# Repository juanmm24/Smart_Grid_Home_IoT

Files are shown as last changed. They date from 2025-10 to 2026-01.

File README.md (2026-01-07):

*** Repository Description *** 

This repository contains all the materials required for the development of an IoT-Based Residential Electricity Consumption Monitoring and Management System.

*** The system is composed of two main nodes *** 

- Node 1: Responsible for measuring electrical consumption and remotely managing household appliances.

- Node 2: Responsible for measuring the overall household electricity consumption and remotely managing electrical circuits.

*** Electronic Components ***

- ESP32 Module

- PZEM-004T V3 Sensor

- 2-Channel Relay Module

- Solid-State Relays (SSR)

* For more details on the electrical connections and circuit diagrams for each node, refer to the folder “Diagrama de Circuitos” (Circuit Diagram).

*** InfluxDB Database Files ***

The data stored in InfluxDB are divided into 10 split archive files, each identified by a numerical suffix in its folder name.
To access them:

1. Download all parts and place them in the same folder.

2. Open only the file smart_grid_home_parted.7z.001 using 7-Zip; the remaining parts will automatically merge during extraction.

************************ Important **************************
To replicate the project, the repository contains all the necessary documents step by step. 
In this sense, the order of the documents to be followed is as follows:

1. 01 AWS Instance Recuses
2. 02 Service Deployment
3. 03 Upload Configuration Files
4. 04 System Installation Guide.pdf

Each document has all the necessary information for the deployment, configuration and installation of the system

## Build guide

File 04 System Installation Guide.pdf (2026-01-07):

MONITORING AND MANAGEMENT SYSTEM OF RESIDENTIAL ELECTRICITY CONSUMPTION
INSTALLATION

This document presents the steps to follow for the installation of the system.
The system has two nodes. Node 1 for the monitoring and management of household appliances and Node 2, for the monitoring of residential electricity consumption and circuit management.

Installation of Node 1
1. Node 1 is installed in any household outlet. It is recommended that it be in the most fenced to the appliances that are going to be monitored.
2. Turn on the node via the on/off button.

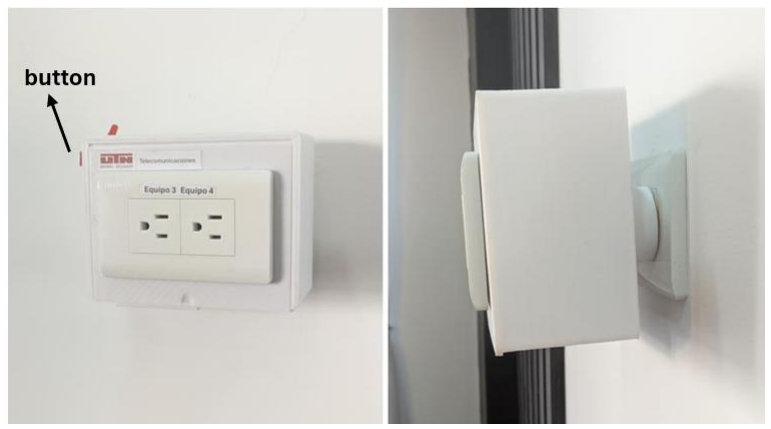
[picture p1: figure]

3. On the Home Assistat platform check the Active Status of the Node.

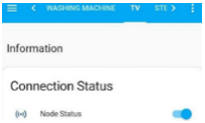
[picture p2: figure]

4. On the outlets of the node, connect the appliances to be monitored

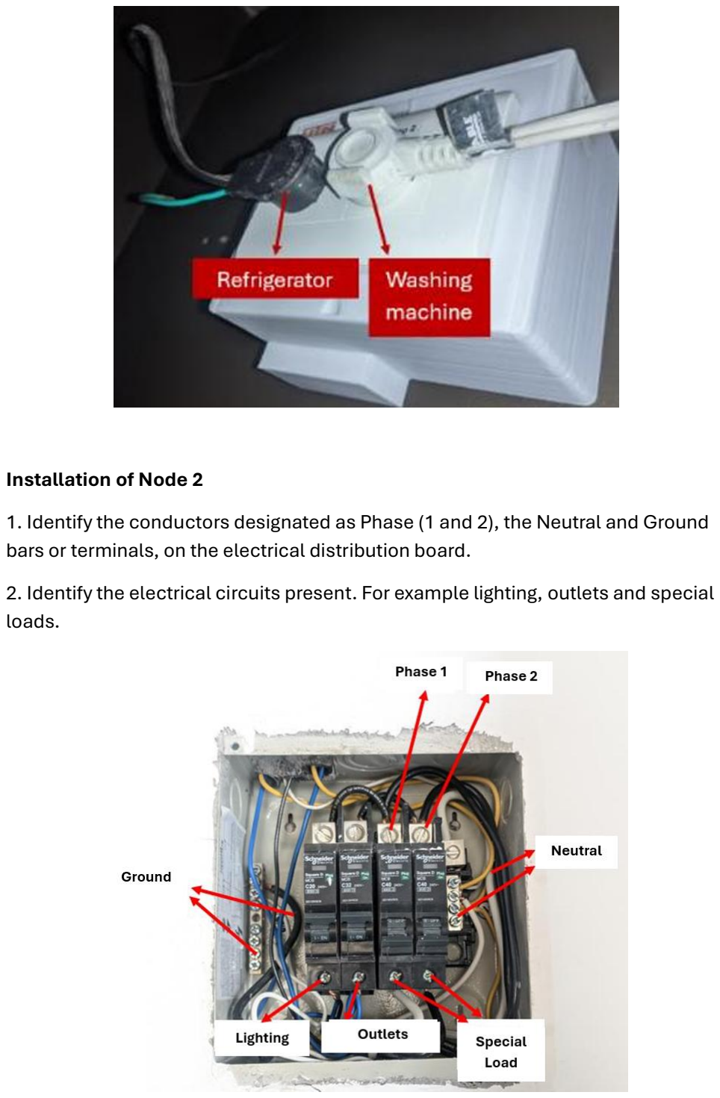
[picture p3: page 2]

Installation of Node 2
1. Identify the conductors designated as Phase (1 and 2), the Neutral and Ground bars or terminals, on the electrical distribution board.
2. Identify the electrical circuits present. For example lighting, outlets and special loads.

3. Relay the connections from the Phase and Neutral terminal block of the distribution board the PZEM004-T sensors, for Phase 1 and Phase 2 voltage measurement.
4. The current transformers (CT) are placed through the conductors designated as Phase 1 and 2, for the current measurement each Phase.
5. Connect the solid-state relays (SSR) individually to each output of the breakers of the electric circuits, to manage the loads by means of activation or deactivation from the ESP32 microcontroller.

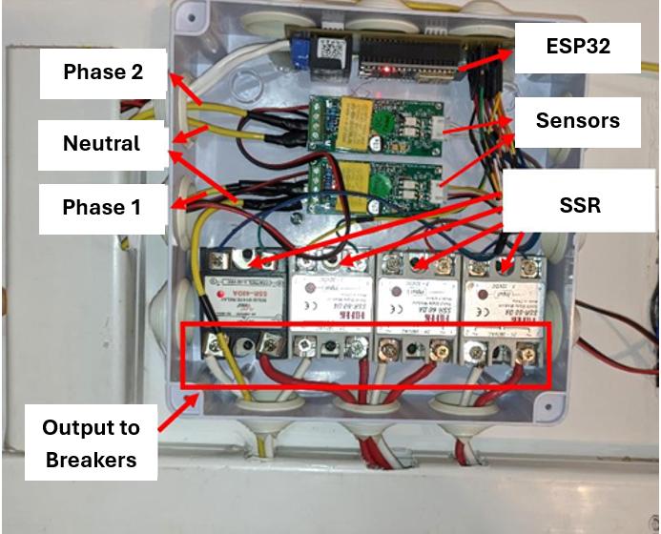
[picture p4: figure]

6. Close and tighten the screws of the top cover of the node, to avoid any electrical risk.

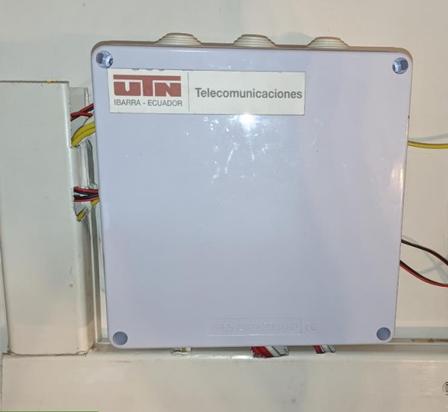
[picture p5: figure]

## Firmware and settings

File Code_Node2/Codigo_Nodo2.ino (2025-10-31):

#include <WiFi.h>                   // Libreria para conexión del ESP32 al Wi-FI                 
#include <PubSubClient.h>           // Libreria para que el microcontrolador 
// sea un cliente MQTT
#include <PZEM004Tv30.h>            // Libreria para funcionamiento y comunicación 
// del sensor pzem004-t y esp32


// Credenciales para conexion a red Wi-Fi

const char* ssid = "XXXXXXX";    // SSID de red Wi-FI a conectarse
const char* password = "XXXXXXX";       // Contrasea de red Wi-FI a conectarse

const char* mqtt_server = "X.X.X.X";  // Direccion IP Broker

WiFiClient espClient3;                      // Creacion de cliente MQTT
PubSubClient client(espClient3);


// Definicion de pines y serial de PZEM-004t del enchufe 1

#define pin_rx_pzem1 32                     // Define pin designado como Rx 
#define pin_tx_pzem1 33                     // Define pin designado como Tx
#define serial_pzem1 Serial1                // Define a la interfaz serial 1

// Definicion de pines y serial de PZEM-004t del enchufe 2
#define pin_rx_pzem2 26                     // Define pin designado como Rx
#define pin_tx_pzem2 27                     // Define pin designado como Tx
#define serial_pzem2 Serial2                // Define a la interfaz serial 2      

// Se define dos objetos de comunicacion serial
// junto con los pines designados como Tx y RX

PZEM004Tv30 pzem_p1(serial_pzem1, pin_rx_pzem1, pin_tx_pzem1);
PZEM004Tv30 pzem_p2(serial_pzem2, pin_rx_pzem2, pin_tx_pzem2);

// Variable booleana del estado del medidorinteligente
bool estado_smart_meter = false;

// Definición de variales para reles

#define pin_ssr1 19         // Variables para pines de señal de control SSR1
#define pin_ssr2 18         // Variables para pines de señal de control SSR2
#define pin_ssr3 5          // Variables para pines de señal de control SSR3
#define pin_ssr4 17         // Variables para pines de señal de control SSR4

///// VARIABLES DEL SENSOR PZEM004T N°1 /////
// Creacion varibles electricas
float voltaje_p1;           // Variable de lectura del voltaje
float corriente_p1;         // Variable de lectura de corriente
float potencia_p1;          // Variable de lectura de potencia
float consumo_p1;           // Variable de lectura de energía o consumo

// Varibles a publicar tipo String al Broker
char pVoltaje_p1[20];       // Variable de publicacion MQTT del voltaje
char pCorriente_p1[20];     // Variable de publicacion MQTT de corriente
char pPotencia_p1[20];      // Variable de publicacion MQTT de potencia
char pConsumo_p1[20];       // Variable de publicacion MQTT de energía o consumo

///// VARIABLES DEL SENSOR PZEM004T N°2 /////
// Creacion varibles electricas
float voltaje_p2;           // Variable de lectura del voltaje
float corriente_p2;         // Variable de lectura de corriente
float potencia_p2;          // Variable de lectura de potencia
float consumo_p2;           // Variable de lectura de energía o consump

// Varibles a publicar tipo String al Broker
char pVoltaje_p2[20];       // Variable de publicacion MQTT del voltaje
char pCorriente_p2[20];     // Variable de publicacion MQTT de corriente
char pPotencia_p2[20];      // Variable de publicacion MQTT de potencia
char pConsumo_p2[20];       // Variable de publicacion MQTT de energía o consumo

//// Variable de Consumo Electrico Total ////
float consumoE_total;       // Variable que almacena el consumo electrico total (suma fase1 y fase 2)
char pConsumoE_total[20];   // Variable de publicacion MQTT del consumo electrico total

// Variables de tiempo para control en la suma del consumo electrico total
unsigned tiempo_actual_sumace = 0;
unsigned tiempo_anterior_sumace = 0;

// Varibles booleandas para control de actualizacion de valores para suma de consumo electrico total
bool actualiza_cE_p1 = false;
bool actualiza_cE_p2 = false;

// Declaracion variables: tiempo de ultima lectura de sensores 1 Y 2

unsigned long tiempo_anterior_p1 = 0;
unsigned long tiempo_anterior_p2 = 0;

const unsigned long intervalo = 10000;        // Intervalo de tiempo para lectura de datos

// Estados de calibracion de sensores
static bool sensor_p1_calibrado = false;      // Estado de caliracion de pzem004t n° 1
static bool sensor_p2_calibrado = false;      // Estado de caliracion de pzem004t n° 2

// Declaracion variables: tiempo de ultima calibracion para sensor-enchufe 1 y 2
unsigned long tanterior_cali_p1 = 0;          // Tiempo última calibreacion pzem004t n° 1
unsigned long tanterior_cali_p2 = 0;          // tiempo última calibreacion pzem004t n° 2

const unsigned long intervalo_calibrar = 5000; // Intervalo de tiempo para calibreacion de sensores

// Variables para el Control del Reseteo de los Dos Sensores Pzem004-t

bool soli_resetE = false;                     // Variable para solicitud de reseteo de energia de los dos sensores pzem004-t

unsigned long tiempo_resetE = 0;              // Variable para el tiempo transcurrido desde inicio de reseteo de Energia de los dos sensores pzem004-t

// Variables para evitar bucle en reseteo de los sensores pzem004-t

bool estado_resetE = false;                   // Variable almacena estado del proceso de reseteo de energia de los dos sensores pzem004-t

unsigned long tiempoU_estadoNodo = 0;
const unsigned long intervalo_estadoNodo = 30000;

//Funcion para conectar el ESP32 a la red Wi-Fi
void setup_wifi() {
  delay(10);                                  // Delay de 10 ms
  Serial.println("Conectando a red Wi-Fi");
  WiFi.mode(WIFI_STA);                        // Modo cliente o estacion del ESP32 con el AP
  WiFi.begin(ssid, password);                 // Metodo para establecer conexion
  while (WiFi.status() != WL_CONNECTED) {     // Bucle para reintentar conexion hasta que sea exitosa
    delay(100);
    Serial.println("Intentando conexion a red Wi-Fi");    // Mensaje sobre proceso de intento conexion Wi-Fi
  }
  Serial.println("Conectado exitosamente a red Wi-Fi");   // Mensaje sobre conexion Wi-Fi exitosa
  Serial.println("La direccion IP asignada es: ");        // Muestra la IP asignada
  Serial.println(WiFi.localIP());
}

// Creacion de funcion para procesamiento de mensajes recibidos del broker

void callback(String topic, byte* message, unsigned int length) { // Funcion con tres argumentos necesarios
  Serial.println();                                               // topic, mensaje y longitud del mensaje
  Serial.print("Mensaje recibido del topic: ");
  Serial.println(topic);                                          // Muestra informacion sbore el topic mediante
  Serial.print("Mensaje: ");                                      // Mediante la interfaz serial
  String message_Estado;                                          // Variable tipo String para almacenar mensaje
  for (int i = 0; i < length; i++)                                // Ciclor for para recorrido de cada byte del mensaje
  {
    Serial.print((char)message[i]);                               // Muestra en N caracter del mensaje
    message_Estado += (char)message[i];                           // Almacena en la variable message_Estado, el
  }                                                               // mensaje completo recibido
  Serial.println("");

  if (topic == "nodo2/c1/ssr1") {                                 // Comparacion con el tema o topic recibido
    if (message_Estado == "On") {                                 // Comparacion del mensaje que contiene el topic
      digitalWrite(pin_ssr1, HIGH);                               // Cambio de estado del SSR1
      Serial.println("Circuito 1  activado");
    } else if (message_Estado == "Off") {                         // Comparacion del mensaje que contiene el topic
      digitalWrite(pin_ssr1, LOW);                                // Cambio de estado del SSR1
      Serial.println("Circuito 1 desactivado");
    }
  } else if (topic == "nodo2/c2/ssr2") {
    if (message_Estado == "On") {                                 // Comparacion del mensaje que contiene el topic
      digitalWrite(pin_ssr2, HIGH);                               // Cambio de estado del SSR2
      Serial.println("Circuito 2 activado");
    } else if (message_Estado == "Off") {                         // Comparacion del mensaje que contiene el topic
      digitalWrite(pin_ssr2, LOW);                                // Cambio de estado del SSR2
      Serial.println("Circuito 2 desactivado");
    }
  } else if (topic == "nodo2/c3/ssr3") {
    if (message_Estado == "On") {                                 // Comparacion del mensaje que contiene el topic
      digitalWrite(pin_ssr3, HIGH);                               // Cambio de estado del SSR3
      Serial.println("Circuito 3 activado");
    } else if (message_Estado == "Off") {                         // Comparacion del mensaje que contiene el topic
      digitalWrite(pin_ssr3, LOW);                                // Cambio de estado del SSR3
      Serial.println("Circuito 3 desactivado");
    }
  } else if (topic == "nodo2/c4/ssr4") {
    if (message_Estado == "On") {                                 // Comparacion del mensaje que contiene el topic
      digitalWrite(pin_ssr4, HIGH);                               // Cambio de estado del SSR4
      Serial.println("Circuito 4 activado");
    } else if (message_Estado == "Off") {                         // Comparacion del mensaje que contiene el topic
      digitalWrite(pin_ssr4, LOW);                                // Cambio de estado del SSR4
      Serial.println("Circuito 4 desactivado");
    }
  } else if (topic == "nodo2/resetE") {                           // Comparacion con el tema o topic recibido
    if (message_Estado == "On" && !estado_resetE) {               // Comparacion del mensaje que contiene el topic
      // Si el mensajes es On y no existe solicitud de reset en curso
      reset_pzem();                                               // Llama a la funcion de reseteo Energia para los dos sensores pzem004-t
      estado_resetE = true;                                       // Cambia el estado de la variable del estado del proceso de reseteo
      client.publish("nodo2/resetE", "Off");                      // Publica el mensaje Off, para confirmar reseteo y evitar bucles de reset
    } else if (message_Estado == "Off") {                         // Comparacion del mensaje que contiene el topic
      estado_resetE = false;                                      // Indica que no hay proceso de reseteo en curso
    }
  }
}

void reset_pzem() {
  if (pzem_p1.resetEnergy() && pzem_p2.resetEnergy()) {           // Verifica si se realiza exitosamente el reseteo de energia de los dos sensores pzem004-t
    Serial.println("Energía de los sensores pzem004-t N°1 y N°2 reseteada exitosamente");
    soli_resetE = true;                                           // Estado de variable para indicar que existe una solicitud de reseteo pendiente
    tiempo_resetE = millis();                                     // Marca el tiempo desde que se inicia el reseteo
    consumoE_total = 0;                                           // Vuelve a cero la variable de consumo electrico total

    consumo_p1 = 0;                                               // Vuelve a cero la variable de consumo pzem1                                          
    consumo_p2 = 0;                                               // Vuelve a cero la variable de consumo pzem2

    dtostrf(consumoE_total, 10, 4, pConsumoE_total);                // Convierte a valor recolectado en una cadena de caracteres
    client.publish("nodo2/consumoe_total", pConsumoE_total);        // Publicación de energia al topic "nodo2/consumoe_total" con valor 0 
    Serial.println("Consumo Electrico Total Reseteado a 0 kWh");
  } else {
    Serial.println("Fallo al resetear la energía de los sensores pzem004-t N°1 y N°2");
  }
}


void reconnect() {                                        // Funcion de reconexión con el broker
  // Reconexion a Broker MQTT
  while (!client.connected()) {                           // Inicio del bucle hasta que el cliente este conectado
    Serial.println("Intentando conexion con el Broker ");
    if (client.connect("espClient3", "nodo2/estado", 1, true, "Off")) {                   // Condicional para intento de conexion con el broker
      Serial.println("Conectado exitosamente al Broker");// si la conexión tiene éxito se realiza lo siguiente:
      client.publish("nodo2/estado", "On", true);         // Publica el estado On cundo se conecta exitosamente
      client.subscribe("nodo2/c1/ssr1");                  // Subscripción del cliente al topic "nodo2/c1/ssr1"
      client.subscribe("nodo2/c2/ssr2");                  // Subscripción del cliente al topic "nodo2/c2/ssr2"
      client.subscribe("nodo2/c3/ssr3");                  // Subscripción del cliente al topic "nodo2/c3/ssr3"
      client.subscribe("nodo2/c4/ssr4");                  // Subscripción del cliente al topic "nodo2/c4/ssr4"
      client.subscribe("nodo2/resetE");                   // Subscripción del cliente al topic "nodo2/resetE""
    } else {                                              // Condicional si la conexón al broker falla
      Serial.print("Fallo conexion con el Broker: ");
      Serial.println(client.state());
    }                                                     // Mensaje de intendo de nueva conexión al broker
    Serial.println("Intentandolo de nuevo");
    // Intentando en 5 segundos
    delay(5000);
  }
}


// LECTURAS DEL PZEM004T N°1

void lecturas_pub_nodo2_p1() {              // Funcion para lectura y publicacion de los datos obtenidos por los sensores

  unsigned long t_actual_p1 = millis();                           // Variable que contiene el tiempo transcurrido desde inicio del ESP32
  if ( (t_actual_p1 - tanterior_cali_p1) >= intervalo_calibrar) { // Condicional que verifica si transcurrio 5 seg. desde la ultima calibracion
    if (!sensor_p1_calibrado) {                                   // Condicional si el sensor aún no ha sido calibrado se calibra
      delay(5000);                                                // Espera 5 segundos en calibrar el sensor
      sensor_p1_calibrado = true;                                 // Marca el sensor como calibrado después de esperar 5 segundos
      return;                                                     // Salir del condicional sin enviar datos antes de calibracion
    }
    tanterior_cali_p1 = t_actual_p1;                              // Actualizacion del nuevo tiempo de la ultima calibracion
  }

  if (soli_resetE && (millis() - tiempo_resetE >= 8000)) {        // Compara si hay una solicitud de reseteo y si se cumple un periodo de 8 segundos inicio de reset
    soli_resetE = false;                                          // Indica que el reseteo termino y finaliza la solicitud de reset
    sensor_p1_calibrado = false;                                  // Designa al sensor pzem1 como no calibrado para volver a calibrar
    sensor_p2_calibrado = false;                                  // Designa al sensor pzem2 como no calibrado para volver a calibrar
  }

  if (!soli_resetE) {                                             // Verifica si no existe solicitud de reseteo de energia para pzem004-t N°1

    // Condicionales para lectura de datos pzem-004t luego de ser calibrado

    unsigned long tiempo_actual_p1 = millis();                   // Variable que contiene el tiempo transcurrido desde inicio del ESP32

    if ( (tiempo_actual_p1 - tiempo_anterior_p1) >= intervalo) { // Condicional que verifica si transcurrio 10 seg. desde la ultima lectura
      // Si se cumple el transcurso de 10 seg. se realizan las sig. acciones
      voltaje_p1 = pzem_p1.voltage();                           // Se realizan las lecturas de los valores de voltaje, corriente
      corriente_p1 = pzem_p1.current();                         // potencia y energía o consumo eléctrico y posterior a ello se
      potencia_p1 = pzem_p1.power();                            // almacenan en las variables designadas a cada una
      consumo_p1 = pzem_p1.energy();

      Serial.println("Mediciones del pzem00t4 N°1");           // Presentacion de los valores obtenidos
      Serial.println("Valor de voltaje: ");
      Serial.print(voltaje_p1, 4);
      Serial.println(" V");
      dtostrf(voltaje_p1, 10, 4, pVoltaje_p1);                 // Convierte a valor recolectado en una cadena de caracteres
      client.publish("nodo2/p1/voltaje", pVoltaje_p1);         // Publicación de voltaje al topic "nodo2/p1/voltaje"

      Serial.println("Valor de corriente: ");                  // Presentacion de los valores obtenidos
      Serial.print(corriente_p1, 4);
      Serial.println(" A");
      dtostrf(corriente_p1, 10, 4, pCorriente_p1);             // Convierte a valor recolectado en una cadena de caracteres
      client.publish("nodo2/p1/corriente", pCorriente_p1);     // Publicación de corriente al topic "nodo2/p1/corriente"

      Serial.println("Valor de potencia: ");                   // Presentacion de los valores obtenidos
      Serial.print(potencia_p1, 4);
      Serial.println(" W");
      dtostrf(potencia_p1, 10, 4, pPotencia_p1);               // Convierte a valor recolectado en una cadena de caracteres
      client.publish("nodo2/p1/potencia", pPotencia_p1);       // Publicación de potencia al topic "nodo2/p1/potencia"

      Serial.println("Valor de consumo: ");                    // Presentacion de los valores obtenidos
      Serial.print(consumo_p1, 4);
      Serial.println(" kWh");
      dtostrf(consumo_p1, 10, 4, pConsumo_p1);                 // Convierte a valor recolectado en una cadena de caracteres
      client.publish("nodo2/p1/consumo", pConsumo_p1);         // Publicación de energia al topic "nodo2/p1/consumo"

      tiempo_anterior_p1 = tiempo_actual_p1;                   // Actualiza el último tiempo de envío
      actualiza_cE_p1 = true;                                  // Confirma actualizacion de valor
    }
  }
}
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
void loop() {

  unsigned long t_actual_estadoN = millis(); // Variable que contiene el tiempo transcurrido desde inicio del ESP32
  if(t_actual_estadoN - tiempoU_estadoNodo >= intervalo_estadoNodo){ // Condicional que verifica si transcurrio 30 seg. desde la ultimo envio de estado
    tiempoU_estadoNodo = t_actual_estadoN;                           // Actualizar el último tiempo de envío
    client.publish("nodo2/estadoPeriodo","On",true);               // Envio del estado del Nodo periodicamente 
  }
  

  if (!client.connected()) {                        // Verifica si el cliente no está conectado a broker MQTT
    reconnect();                                    // Ejecuta la funcion de reconexion al broker
  }

  client.loop();
  lecturas_pub_nodo2_p1();                          // Si el cliente MQTT está conectado, llama a las funciones de lectura y publicación
  lecturas_pub_nodo2_p2();
  calculo_consumoE_total();
}

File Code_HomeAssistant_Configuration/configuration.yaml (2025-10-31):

# Loads default set of integrations. Do not remove.
default_config:

# Load frontend themes from the themes folder
frontend:
  themes: !include_dir_merge_named themes

automation: !include automations.yaml
script: !include scripts.yaml
scene: !include scenes.yaml


# Creación de calendarios para consultas del consumo eléctrico nodo1_1 y nodo1_2

# Dispositivo 1
input_datetime:

  calendario_nodo1_1_t1:
    name: "Calendario nodo1_1_t1"
    has_date: true
    has_time: false

  calendario_nodo1_1_t2:
    name: "Calendario nodo1_1_t2"
    has_date: true
    has_time: false

  calendario_nodo1_2_t1:
    name: "Calendario nodo1_2_t1"
    has_date: true
    has_time: false

  calendario_nodo1_2_t2:
    name: "Calendario nodo1_2_t2"
    has_date: true
    has_time: false

  calendario_nodo2_p1:
    name: "Calendario nodo2_p1"
    has_date: true
    has_time: false
    
  calendario_nodo2_p2:
    name: "Calendario nodo2_p2"
    has_date: true
    has_time: false

  calendario_nodo2_ce_total:
    name: "Calendario nodo2_ce_total"
    has_date: true
    has_time: false
  
  calendario_nodo2_cet_fechai:
    name: "Calendario nodo2_cet_fechai"
    has_date: true
    has_time: false
    
  calendario_nodo2_cet_fechaf:
    name: "Calendario nodo2_cet_fechaf"
    has_date: true
    has_time: false  


    
# Creacion de Botones para las Consultas de Consumo Electricos
input_button:

  enviar_fecha_nodo1_1_t1:
    name: Enviar Fecha Nodo1_1_t1
    
  enviar_fecha_nodo1_1_t2:
    name: Enviar Fecha Nodo1_1_t2

  enviar_fecha_nodo1_2_t1:
    name: Enviar Fecha Nodo1_2_t1
    
  enviar_fecha_nodo1_2_t2:
    name: Enviar Fecha Nodo1_2_t2

  enviar_fecha_nodo2_p1:
    name: Enviar Fecha Nodo2_p1

  enviar_fecha_nodo2_p2:
    name: Enviar Fecha Nodo2_p2
    
  enviar_fecha_nodo2_ce_total:
    name: Enviar Fecha Nodo2_ce_total
    
  enviar_fecha_nodo2_cet_rangos:
    name: Enviar Fecha Nodo2_cet_rangos

# Creacion de Entrada para Valores de Pontencia Nomimal

input_number:
#Dispositivo 1
  potencia_nominal_nodo1_1_t1:
    name: Potencia Nominal Nodo1_1_t1
    min: 0
    max: 1000
    step: 0.5  # Permite ingresar valores decimales
    unit_of_measurement: "W"
    mode: box

#Dispositivo 2
  potencia_nominal_nodo1_1_t2:
    name: Potencia Nominal Nodo1_1_t2
    min: 0
    max: 1000
    step: 0.5  # Permite ingresar valores decimales
    unit_of_measurement: "W"
    mode: box
    
#Dispositivo 3
  potencia_nominal_nodo1_2_t1:
    name: Potencia Nominal Nodo1_2_t1
    min: 0
    max: 1000
    step: 0.5  # Permite ingresar valores decimales
    unit_of_measurement: "W"
    mode: box
    
#Dispositivo 4
  potencia_nominal_nodo1_2_t2:
    name: Potencia Nominal Nodo1_2_t2
    min: 0
    max: 1000
    step: 0.5  # Permite ingresar valores decimales
    unit_of_measurement: "W"
    mode: box

mqtt:

# Creacion de Sensores MQTT para recibir mensajes a traves de topicos de variables electricas

    sensor:
    
#Dispositivo 1 
    - name: "Voltaje Nodo1_1 Tomacorriente 1"
      state_topic: "nodo1_1/t1/voltaje"
      qos: 0
      unit_of_measurement: "V"
      
    - name: "Corriente Nodo1_1 Tomacorriente 1"
      state_topic: "nodo1_1/t1/corriente"
      qos: 0
      unit_of_measurement: "A"
      
    - name: "Potencia Nodo1_1 Tomacorriente 1"
      state_topic: "nodo1_1/t1/potencia"
      qos: 0
      unit_of_measurement: "W"   
      
    - name: "Consumo_E Nodo1_1 Tomacorriente 1"
      state_topic: "nodo1_1/t1/consumo"
      qos: 0
      unit_of_measurement: "kWh"
      
#Dispositivo 2      
    - name: "Voltaje Nodo1_1 Tomacorriente 2"
      state_topic: "nodo1_1/t2/voltaje"
      qos: 0
      unit_of_measurement: "V"
      
    - name: "Corriente Nodo1_1 Tomacorriente 2"
      state_topic: "nodo1_1/t2/corriente"
      qos: 0
      unit_of_measurement: "A"
      
    - name: "Potencia Nodo1_1 Tomacorriente 2"
      state_topic: "nodo1_1/t2/potencia"
      qos: 0
      unit_of_measurement: "W"
      
    - name: "Consumo_E Nodo1_1 Tomacorriente 2"
      state_topic: "nodo1_1/t2/consumo"
      qos: 0
      unit_of_measurement: "kWh"
      
#Dispositivo 3 
    - name: "Voltaje Nodo1_2 Tomacorriente 1"
      state_topic: "nodo1_2/t1/voltaje"
      qos: 0
      unit_of_measurement: "V"
      
    - name: "Corriente Nodo1_2 Tomacorriente 1"
      state_topic: "nodo1_2/t1/corriente"
      qos: 0
      unit_of_measurement: "A"
      
    - name: "Potencia Nodo1_2 Tomacorriente 1"
      state_topic: "nodo1_2/t1/potencia"
      qos: 0
      unit_of_measurement: "W"   
      
    - name: "Consumo_E Nodo1_2 Tomacorriente 1"
      state_topic: "nodo1_2/t1/consumo"
      qos: 0
      unit_of_measurement: "kWh"
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

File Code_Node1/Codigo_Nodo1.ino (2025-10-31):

#include <WiFi.h>                   // Libreria para conexión del ESP32 al Wi-FI                 
#include <PubSubClient.h>           // Libreria para que el microcontrolador 
                                    // sea un cliente MQTT
#include <PZEM004Tv30.h>            // Libreria para funcionamiento y comunicación 
                                    // del sensor pzem004-t y esp32
                                    

// Credenciales para conexion a red Wi-Fi

const char* ssid = "XXXXXXX";    // SSID de red Wi-FI a conectarse
const char* password = "XXXXXXXX";       // Contraseña de red Wi-FI a conectarse

const char* mqtt_server = "X.X.X.X"; // Direccion IP Broker

WiFiClient espClient1;                      // Creacion de cliente MQTT
PubSubClient client(espClient1);


// Definicion de pines y serial de PZEM-004t del enchufe 1

#define pin_rx_pzem1 32                     // Define pin designado como Rx 
#define pin_tx_pzem1 33                     // Define pin designado como Tx
#define serial_pzem1 Serial1                // Define a la interfaz serial 1

// Definicion de pines y serial de PZEM-004t del enchufe 2
#define pin_rx_pzem2 26                     // Define pin designado como Rx
#define pin_tx_pzem2 27                     // Define pin designado como Tx
#define serial_pzem2 Serial2                // Define a la interfaz serial 2      

// Se define dos objetos de comunicacion serial
// junto con los pines designados como Tx y RX

PZEM004Tv30 pzem_t1(serial_pzem1, pin_rx_pzem1, pin_tx_pzem1);
PZEM004Tv30 pzem_t2(serial_pzem2, pin_rx_pzem2, pin_tx_pzem2);


// Pines y variables para el rele del enchufe 1
#define pin_t1 14                 // Designa al pin de salida para comunicar con el rele
bool estado_relay_t1 = false;     // Estado que evita el inicio activado el rele

// Pines y variables para el rele del enchufe 2
#define pin_t2 25                 // Designa al pin de salida para comunicar con el rele
bool estado_relay_t2 = false;     // Estado que evita el inicio activado el rele


///// VARIABLES DEL PZEM00T DEL ENCHUFE 1 /////
// Creacion varibles electricas
float voltaje_t1;           // Variable de lectura del voltaje
float corriente_t1;         // Variable de lectura de corriente
float potencia_t1;          // Variable de lectura de potencia
float consumo_t1;           // Variable de lectura de energía o consumo

// Varibles a publicar tipo String a Broker
char pVoltaje_t1[20];       // Variable de publicacion MQTT del voltaje
char pCorriente_t1[20];     // Variable de publicacion MQTT de corriente
char pPotencia_t1[20];      // Variable de publicacion MQTT de potencia
char pConsumo_t1[20];       // Variable de publicacion MQTT de energía o consumo

///// VARIABLES DEL PZEM00T DEL ENCHUFE 2 /////
// Creacion varibles electricas
float voltaje_t2;           // Variable de lectura del voltaje
float corriente_t2;         // Variable de lectura de corriente
float potencia_t2;          // Variable de lectura de potencia
float consumo_t2;           // Variable de lectura de energía o consump

// Varibles a publicar tipo String a Broker
char pVoltaje_t2[20];       // Variable de publicacion MQTT del voltaje
char pCorriente_t2[20];     // Variable de publicacion MQTT de corriente
char pPotencia_t2[20];      // Variable de publicacion MQTT de potencia
char pConsumo_t2[20];       // Variable de publicacion MQTT de energía o consumo


// Declaracion variables: tiempo de ultima lectura de sensores-enchufes 1 y 2

unsigned long tiempo_anterior_t1 = 0;
unsigned long tiempo_anterior_t2 = 0;

const unsigned long intervalo = 10000;        // Intervalo de tiempo para lectura de datos

// Estados de calibracion de sensores
static bool sensor_t1_calibrado = false;      // Estado de caliracion de tomacorriente 1
static bool sensor_t2_calibrado = false;      // Estado de caliracion de tomacorriente 2

// Declaracion variables: tiempo de ultima calibracion para sensor-enchufe 1 y 2
unsigned long tanterior_cali_t1 = 0;          // Tiempo última calibreacion sensor-tomacorriente 1
unsigned long tanterior_cali_t2 = 0;          // tiempo última calibreacion sensor-tomacorriente 2

const unsigned long intervalo_calibrar = 5000; // Intervalo de tiempo para calibreacion de sensores

// Variables para el Control del Reseteo Sensores Pzem004-t

bool soli_resetE_t1 = false;                  // Variable para solicitud de reseteo de energia pzem004-t del tomacorriente 1
bool soli_resetE_t2 = false;                  // Variable para solicitud de reseteo de energia pzem004-t del tomacorriente 2

unsigned long tiempo_resetE_t1 = 0;           // Variable para el tiempo transcurrido desde inicio de reseteo de Energia tomacorriente 1
unsigned long tiempo_resetE_t2 = 0;           // Variable para el tiempo transcurrido desde inicio de reseteo de Energia tomacorriente 2

// Variables para evitar bucle en reseteo de los sensores pzem004-t

bool estado_resetE_t1 = false;                // Variable almacena estado del proceso de reseteo de energia tomacorriente 1
bool estado_resetE_t2 = false;                // Variable almacena estado del proceso de reseteo de energia tomacorriente 2


// Variables para envío de estado del Nodo

unsigned long tiempoU_estadoNodo = 0;
const unsigned long intervalo_estadoNodo = 30000;

//Funcion para conectar el ESP32 a la red Wi-Fi
void setup_wifi() {
  delay(10);                                  // Delay de 10 ms
  Serial.println("Conectando a red Wi-Fi");
  WiFi.mode(WIFI_STA);                        // Modo cliente o estacion del ESP32 con el AP
  WiFi.begin(ssid, password);                 // Metodo para establecer conexion
  while (WiFi.status() != WL_CONNECTED) {     // Bucle para reintentar conexion hasta que sea exitosa
    delay(100);
    Serial.println("Intentando conexion a red Wi-Fi");    // Mensaje sobre proceso de intento conexion Wi-Fi
  }
  Serial.println("Conectado exitosamente a red Wi-Fi");   // Mensaje sobre conexion Wi-Fi exitosa
  Serial.println("La direccion IP asignada es: ");        // Muestra la IP asignada
  Serial.println(WiFi.localIP());
}

// Creacion de funcion para procesamiento de mensajes recibidos del broker
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
